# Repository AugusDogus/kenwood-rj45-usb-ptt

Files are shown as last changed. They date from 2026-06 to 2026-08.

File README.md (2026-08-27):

# kenwood-rj45-usb-ptt

USB push-to-talk adapter for Kenwood-style RJ45 handheld microphones such as KMC-30 / KMC-32 compatible mics.

## Why

The goal is a CB-radio-style handheld PTT mic for a computer, and nothing off the shelf does the whole job. USB PTT mics are desktop/gooseneck units, handheld dispatch mics with the right feel are not USB (XLR, RJ45, or radio-specific plugs) and need extra hardware, and USB handheld mics have no PTT switch. Level-triggered or software PTT is unreliable; the mic's physical switch should be the trigger.

This adapter closes that gap: plug in a cheap, widely available Kenwood-style RJ45 hand mic and the board shows up as a standard USB audio microphone plus a USB HID keyboard that holds F13 while PTT is pressed, so any app with a push-to-talk keybind (Discord, Mumble, dispatch software) works with no drivers or custom software.

Rev A is a PCBWay-assemblable board. It uses a Seeed XIAO RP2040 module for USB and firmware, an MCP6002 analog front-end for the microphone, and an RJ45 jack for the hand mic.

## What To Upload To PCBWay

Use the release assets from `v0.1.0`, or the matching files in `manufacturing/revA/`:

- `kenwood-rj45-usb-ptt-revA-fabrication.zip` for PCB fabrication Gerbers/drill
- `BOM_pcbway_revA.csv` for assembly BOM
- `positions_revA.csv` for pick-and-place / centroid
- `PCBWAY_NOTES_revA.md` for assembly notes

`manufacturing/revA/ORDER_INSTRUCTIONS.md` has the same checklist in upload order.

## Current Status

- KiCad DRC: 0 violations
- Unconnected items: 0
- Firmware: not implemented yet
- First hardware spin: order a small quantity only

## Repository Layout

- `hardware/kicad/` - KiCad 9 project, board, schematic, and vendored footprint/symbol libraries
- `manufacturing/revA/` - PCBWay-ready fabrication and assembly outputs
- `firmware/` - firmware plan and future XIAO RP2040 code
- `tools/` - board generation helper used for Rev A
- `docs/` - design/order notes

## Rev A Architecture

```text
Kenwood RJ45 hand mic
  mic audio -> electret bias -> MCP6002 preamp -> XIAO RP2040 ADC -> USB audio microphone
  PTT       -> debounced GPIO -> XIAO RP2040 USB HID keyboard -> F13 while held

Computer USB-C -> exposed USB-C connector on Seeed XIAO RP2040 module
```

RJ45 pin 2 is intentionally left open. Some Kenwood-style radios provide accessory power on that pin, but Rev A does not feed voltage into it.

## Open In KiCad

Open:

`hardware/kicad/radio-mic-usb-ptt.kicad_pro`

The KiCad project uses project-relative library tables, so it should open from this repo without global library setup.

## Regenerate Rev A Board

The final board file is already generated and routed. To regenerate the unrouted board from the helper script:

```sh
NO_ROUTES=1 python3 tools/generate_revA_board.py
```

Then autoroute/import in KiCad or with the MCP tooling. Do not run multi-attempt autorouting unless you explicitly want multiple confirmation prompts.

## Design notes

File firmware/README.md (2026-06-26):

# Firmware Plan

Target: Seeed XIAO RP2040.

Required USB functions:

- USB HID keyboard: hold `F13` while `PTT_GPIO` is active.
- USB Audio Class microphone: stream ADC samples from `MIC_ADC`.

Rev A pin mapping:

| Function | XIAO pin | RP2040 GPIO | Schematic net |
| --- | --- | ---: | --- |
| Mic ADC | D0 | GPIO26 / ADC0 | `MIC_ADC` |
| PTT input | D6 | GPIO0 | `PTT_GPIO` |
| Optional UP input | D7 | GPIO1 | `UP_GPIO` |
| Optional DOWN input | D8 | GPIO2 | `DOWN_GPIO` |
| PTT/status LED | D10 | GPIO3 | `PTT_LED_DRIVE` |

Recommended firmware stack:

- Pico SDK
- TinyUSB device stack
- Composite USB descriptors for Audio Class + HID keyboard

PTT behavior:

```c
if (ptt_pressed && !held) {
    hid_keyboard_press(F13);
    held = true;
}

if (!ptt_pressed && held) {
    hid_keyboard_release(F13);
    held = false;
}
```

Audio behavior:

- Sample ADC0 at a speech-oriented rate such as 16 kHz or 48 kHz.
- Center samples around the ADC midscale produced by the analog `VREF` circuit.
- Present mono 16-bit PCM over USB Audio Class.

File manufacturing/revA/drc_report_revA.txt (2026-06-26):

** Drc report for radio-mic-usb-ptt.kicad_pcb **
** Created on 2026-06-25T22:26:27 **
** Report includes: Errors, Warnings **

** Found 0 DRC violations **

** Found 0 unconnected pads **

** Found 0 Footprint errors **

** Ignored checks **
    - Footprint has no courtyard defined
    - Track endpoint not centered on via
    - Tuning profile track geometries
    - Footprint doesn't match symbol's footprint filters
    - PTH inside courtyard
    - NPTH inside courtyard
    - Footprint component type doesn't match footprint pads

** End of Report **

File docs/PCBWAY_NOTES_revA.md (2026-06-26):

# PCBWay Rev A Assembly Notes

## Assembly Intent

This is intended as a fully assembled PCBWay PCBA order. The Seeed XIAO RP2040 is treated as an SMD castellated module, not as a hand-soldered development board.

## Do Not Populate / Do Not Install

- Rev A does not connect RJ45 pin 2 to anything. This intentionally avoids feeding power into an unknown microphone accessory-power pin.
- There are no DNP components in the final Rev A PCBWay BOM.

## Through-Hole Parts

- `J1` is an RJ45 through-hole connector footprint.
- `TP1`-`TP4` are test pads and can be omitted if PCBWay treats them as through-hole assembly cost adders.
- Mounting holes are NPTH and should not be plated.

## Placement Intent

- RJ45 mic jack should sit on the left edge of the board.
- XIAO RP2040 USB-C connector should be exposed on the opposite edge.
- Keep `MIC_RAW`, `MIC_AC`, `VREF`, and `MIC_ADC` traces short and away from digital GPIO where practical.
- Put `C5` close to `U2` VDD/VSS.
- Put `C3` close to the XIAO ADC input pad.

## Required Order Files

PCBWay requests these for PCBA:

- Gerbers
- Drill files
- BOM CSV/XLSX
- Pick-and-place / centroid / XYRS file

Use `manufacturing/revA/BOM_pcbway_revA.csv` as the assembly BOM for Rev A.

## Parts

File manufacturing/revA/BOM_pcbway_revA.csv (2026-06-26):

Line | Qty | References | Value | Footprint | Type | Manufacturer | Manufacturer Part Number | Notes
1 | 1 | U1 | Seeed XIAO RP2040 | XIAO-RP2040-SMD | SMD module | Seeed Studio | 102010428 | Castellated module; confirm PCBWay can source or consign
2 | 1 | U2 | MCP6002T-E/MS | MSOP-8_3x3mm_P0.65mm | SMD | Microchip | MCP6002T-E/MS | Dual rail-to-rail op amp
3 | 1 | J1 | KMC RJ45 MIC | RJ45_Amphenol_RJHSE5380 | Through-hole | Amphenol | RJHSE-5380 | 8P8C RJ45 jack
4 | 1 | R1 | 2.2k | R_0603_1608Metric | SMD | Generic | 0603 1% | Electret mic bias
5 | 3 | R2 R3 R13 | 100k | R_0603_1608Metric | SMD | Generic | 0603 1% | VREF divider and input bias
6 | 2 | R4 R7 | 10k | R_0603_1608Metric | SMD | Generic | 0603 1% | Gain resistor and PTT pull-up
7 | 1 | R5 | 200k | R_0603_1608Metric | SMD | Generic | 0603 1% | Preamp feedback gain resistor
8 | 3 | R6 R8 R11 | 1k | R_0603_1608Metric | SMD | Generic | 0603 1% | GPIO/ADC/LED series resistors
9 | 2 | C1 C2 | 1uF | C_0603_1608Metric | SMD | Generic | 0603 X5R/X7R | Audio coupling and VREF filter
10 | 1 | C3 | 1nF | C_0603_1608Metric | SMD | Generic | 0603 C0G/X7R | ADC low-pass filter
11 | 2 | C4 C5 | 100nF | C_0603_1608Metric | SMD | Generic | 0603 X7R | PTT debounce and op-amp decoupling
12 | 1 | D1 | PTT_LED | LED_0603_1608Metric | SMD | Generic | 0603 LED | Firmware-driven status LED

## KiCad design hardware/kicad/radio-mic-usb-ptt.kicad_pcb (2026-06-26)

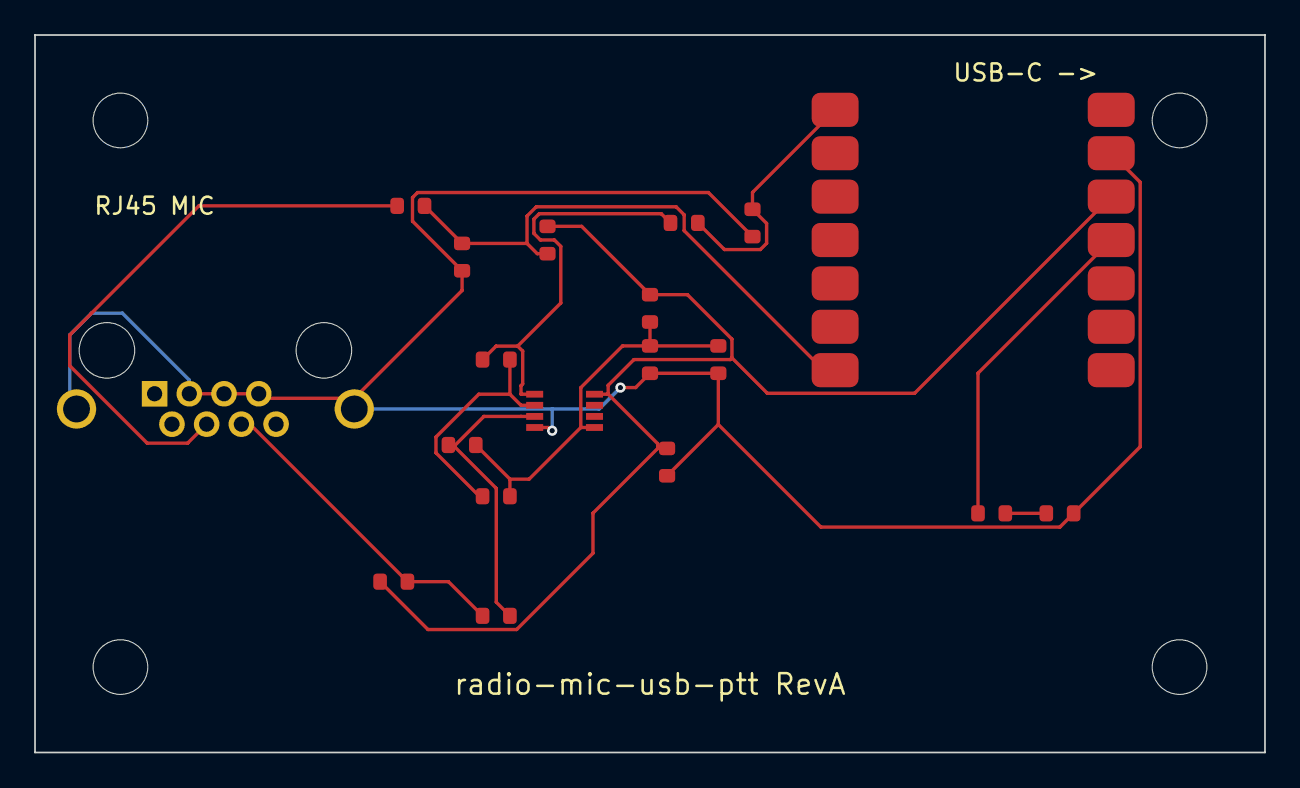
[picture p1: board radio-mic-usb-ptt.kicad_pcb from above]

Board: 2 copper layers, 72.0 x 42.0 mm, 23 parts (0 on the bottom side), 12 nets.

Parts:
C1, C2: 1uF; C_0603_1608Metric
C3: 1nF; C_0603_1608Metric
C4, C5: 100nF; C_0603_1608Metric
D1: PTT_LED; LED_0603_1608Metric
H1, H2, H3, H4: MountingHole_3.2mm
J1: KMC RJ45 MIC; RJ45_Amphenol_RJHSE5380
R1: 2.2k; R_0603_1608Metric
R2, R3, R13: 100k; R_0603_1608Metric
R4, R7: 10k; R_0603_1608Metric
R5: 200k; R_0603_1608Metric
R6, R8, R11: 1k; R_0603_1608Metric
U1: Seeed XIAO RP2040; XIAO-RP2040-SMD
U2: MCP6002T-E/MS; MSOP-8_3x3mm_P0.65mm

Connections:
+3V3: C5.1, R1.1, R2.1, R7.1, U1.12, U2.8
GND: C2.2, C3.2, C4.2, C5.2, D1.2, J1.3, J1.5, J1.7, J1.SH, R3.2, U1.13, U2.4
LED_A: D1.1, R11.2
MIC_AC: C1.2, R13.1, U2.3
MIC_ADC: C3.1, R6.2, U1.1
MIC_AMP: R5.1, R6.1, U2.1
MIC_RAW: C1.1, J1.6, R1.2
NINV: R4.1, R5.2, U2.2
PTT_GPIO: C4.1, R7.2, R8.2, U1.7
PTT_LED_DRIVE: R11.1, U1.11
PTT_RAW: J1.4, R8.1
VREF: C2.1, R2.2, R3.1, R4.2, R13.2, U2.5

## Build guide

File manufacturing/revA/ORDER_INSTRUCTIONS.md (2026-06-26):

# PCBWay Rev A Order Instructions

Upload these files for a PCB + assembly order:

- PCB fabrication: `kenwood-rj45-usb-ptt-revA-fabrication.zip` release asset, or zip the files in `gerbers/` and `drill/`
- Assembly BOM: `BOM_pcbway_revA.csv`
- Pick-and-place / centroid: `positions_revA.csv`
- Notes: `PCBWAY_NOTES_revA.md`

Important assembly notes:

- Rev A is top-side assembly only.
- RJ45 pin 2 is intentionally left open.
- There are no DNP parts in the final Rev A BOM.
- Confirm whether PCBWay can source `U1` Seeed Studio XIAO RP2040, MPN `102010428`. If not, order it as consigned/kitted assembly or revise to a bare RP2040 design later.

Validation status:

- KiCad 9.0.9 DRC was run.
- DRC has zero violations and zero unconnected items.

Do not order large quantities from Rev A. This is the first hardware spin and still needs mic pinout and firmware validation.

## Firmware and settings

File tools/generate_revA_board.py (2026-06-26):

#!/usr/bin/env python3
from pathlib import Path
import os
from uuid import uuid4

ROOT = Path(__file__).resolve().parents[1]
BOARD = ROOT / "hardware" / "kicad" / "radio-mic-usb-ptt.kicad_pcb"

NETS = {
    "": 0,
    "GND": 1,
    "+3V3": 2,
    "MIC_RAW": 3,
    "MIC_AC": 4,
    "VREF": 5,
    "NINV": 6,
    "MIC_AMP": 7,
    "MIC_ADC": 8,
    "PTT_RAW": 9,
    "PTT_GPIO": 10,
    "UP_RAW": 11,
    "UP_GPIO": 12,
    "DOWN_RAW": 13,
    "DOWN_GPIO": 14,
    "PTT_LED_DRIVE": 15,
    "LED_A": 16,
    "MIC_PWR": 17,
    "SPARE_B": 18,
}


def u():
    return str(uuid4())


def net(name):
    return f'(net {NETS[name]} "{name}")' if name else '(net 0 "")'


def pad_net(name):
    return f'(net {NETS[name]} "{name}")' if name else ''


def xy(n):
    return f"{n:.3f}".rstrip("0").rstrip(".")


def prop(name, value, x, y, layer="F.Fab", hide=True):
    h = " hide" if hide else ""
    return f'''    (property "{name}" "{value}" (at {xy(x)} {xy(y)} 0) (layer "{layer}"){h}
      (effects (font (size 1 1) (thickness 0.15)))
    )'''


def fp_header(lib, name, ref, value, x, y, rot=0, attr="smd"):
    # Footprints are embedded directly in the board. Leaving off the library
    # nickname avoids KiCad DRC warnings about generated geometry not matching
    # a separate footprint library copy.
    return f'''  (footprint "{name}"
    (layer "F.Cu")
    (uuid "{u()}")
    (at {xy(x)} {xy(y)} {rot})
{prop("Reference", ref, 0, -1.6, "F.Fab", True)}
{prop("Value", value, 0, 1.6, "F.Fab", True)}
    (attr {attr})'''


def fp_end():
    return "  )"


def two_pad(lib, name, ref, value, x, y, nets, rot=0, dnp=False):
    attr = "smd" + (" dnp" if dnp else "")
    lines = [fp_header(lib, name, ref, value, x, y, 0, attr)]
    if rot == 90:
        p1 = (0, -0.8, 90)
        p2 = (0, 0.8, 90)
    else:
        p1 = (-0.8, 0, 0)
        p2 = (0.8, 0, 0)
    lines += [
        '    (fp_rect (start -1.55 -0.75) (end 1.55 0.75) (stroke (width 0.05) (type default)) (fill none) (layer "F.CrtYd") (uuid "%s"))' % u(),
        f'    (pad "1" smd roundrect (at {xy(p1[0])} {xy(p1[1])} {p1[2]}) (size 0.8 0.95) (layers "F.Cu" "F.Paste" "F.Mask") (roundrect_rratio 0.25) {pad_net(nets[0])} (uuid "{u()}"))',
        f'    (pad "2" smd roundrect (at {xy(p2[0])} {xy(p2[1])} {p2[2]}) (size 0.8 0.95) (layers "F.Cu" "F.Paste" "F.Mask") (roundrect_rratio 0.25) {pad_net(nets[1])} (uuid "{u()}"))',
        fp_end(),
    ]
    return "\n".join(lines)


def testpoint(ref, value, x, y, netname):
    return f'''  (footprint "TestPoint_THTPad_D1.5mm"
    (layer "F.Cu")
    (uuid "{u()}")
    (at {xy(x)} {xy(y)} 0)
{prop("Reference", ref, 0, -1.5)}
{prop("Value", value, 0, 1.5, "F.Fab", True)}
    (attr exclude_from_pos_files)
    (pad "1" thru_hole circle (at 0 0) (size 1.5 1.5) (drill 0.7) (layers "*.Cu" "*.Mask") {pad_net(netname)} (uuid "{u()}"))
  )'''


def mounting(ref, x, y):
    return f'''  (footprint "MountingHole_3.2mm"
    (layer "F.Cu")
    (uuid "{u()}")
    (at {xy(x)} {xy(y)} 0)
{prop("Reference", ref, 0, -2)}
{prop("Value", "MountingHole_3.2mm", 0, 2, "F.Fab", True)}
    (attr exclude_from_pos_files exclude_from_bom)
    (pad "" np_thru_hole circle (at 0 0) (size 3.2 3.2) (drill 3.2) (layers "*.Cu" "*.Mask") (uuid "{u()}"))
  )'''


def rj45():
    x, y = 7, 21
    pad_defs = [
        ("1", 0, 0, "rect", ""),
        ("3", 2.032, 0, "circle", "GND"),
        ("5", 4.064, 0, "circle", "GND"),
        ("7", 6.096, 0, "circle", "GND"),
        ("2", 1.016, 1.78, "circle", ""),
        ("4", 3.048, 1.78, "circle", "PTT_RAW"),
        ("6", 5.08, 1.78, "circle", "MIC_RAW"),
        ("8", 7.112, 1.78, "circle", ""),
    ]
    lines = [fp_header("Connector_RJ", "RJ45_Amphenol_RJHSE5380", "J1", "KMC RJ45 MIC", x, y, 0, "through_hole")]
    lines += [
        '    (fp_rect (start -6.22 -8.5) (end 13.34 8.25) (stroke (width 0.05) (type default)) (fill none) (layer "F.CrtYd") (uuid "%s"))' % u(),
    ]
    for num, px, py, shape, netname in pad_defs:
        lines.append(f'    (pad "{num}" thru_hole {shape} (at {xy(px)} {xy(py)} 0) (size 1.5 1.5) (drill 0.89) (layers "*.Cu" "*.Mask") {pad_net(netname)} (uuid "{u()}"))')
    lines += [
        f'    (pad "" np_thru_hole circle (at -2.79 -2.54 0) (size 3.25 3.25) (drill 3.25) (layers "*.Cu" "*.Mask") (uuid "{u()}"))',
        f'    (pad "" np_thru_hole circle (at 9.91 -2.54 0) (size 3.25 3.25) (drill 3.25) (layers "*.Cu" "*.Mask") (uuid "{u()}"))',
        f'    (pad "SH" thru_hole circle (at 11.69 0.89 0) (size 2.3 2.3) (drill 1.57) (layers "*.Cu" "*.Mask") {pad_net("GND")} (uuid "{u()}"))',
        f'    (pad "SH" thru_hole circle (at -4.57 0.89 0) (size 2.3 2.3) (drill 1.57) (layers "*.Cu" "*.Mask") {pad_net("GND")} (uuid "{u()}"))',
        fp_end(),
    ]
    return "\n".join(lines)


def xiao():
    x, y = 46, 22.5
    nets = {
        "1": "MIC_ADC", "7": "PTT_GPIO",
        "11": "PTT_LED_DRIVE", "12": "+3V3", "13": "GND", "18": "GND", "20": "GND",
    }
    pads = [
        ("1", 0.835, -18.12, 2.75, 2, 0), ("2", 0.835, -15.58, 2.75, 2, 0),
        ("3", 0.835, -13.04, 2.75, 2, 0), ("4", 0.835, -10.5, 2.75, 2, 0),
        ("5", 0.835, -7.96, 2.75, 2, 0), ("6", 0.835, -5.42, 2.75, 2, 0),
        ("7", 0.835, -2.88, 2.75, 2, 0), ("8", 17, -2.88, 2.75, 2, 0),
        ("9", 17, -5.42, 2.75, 2, 0), ("10", 17, -7.96, 2.75, 2, 0),
        ("11", 17, -10.5, 2.75, 2, 0), ("12", 17, -13.04, 2.75, 2, 0),
        ("13", 17, -15.58, 2.75, 2, 0), ("14", 17, -18.12, 2.75, 2, 0),
    ]
    lines = [fp_header("Seeed_Studio_XIAO_Series", "XIAO-RP2040-SMD", "U1", "Seeed XIAO RP2040", x, y, 0, "smd")]
    lines += [
        '    (fp_rect (start 0 -21) (end 17.8 0) (stroke (width 0.05) (type default)) (fill none) (layer "F.CrtYd") (uuid "%s"))' % u(),
    ]
    for num, px, py, sx, sy, circle in pads:
        shape = "circle" if circle else "roundrect"
        rr = "" if circle else "(roundrect_rratio 0.25)"
        lines.append(f'    (pad "{num}" smd {shape} (at {xy(px)} {xy(py)} 0) (size {xy(sx)} {xy(sy)}) (layers "F.Cu" "F.Paste" "F.Mask") {rr} {pad_net(nets.get(num, ""))} (uuid "{u()}"))')
    lines.append(fp_end())
    return "\n".join(lines)


def msop():
    x, y = 31, 22
    nets = {"1":"MIC_AMP", "2":"NINV", "3":"MIC_AC", "4":"GND", "5":"VREF", "6":"", "7":"", "8":"+3V3"}
    pads = [("1",-1.75,-0.975),("2",-1.75,-0.325),("3",-1.75,0.325),("4",-1.75,0.975),("5",1.75,0.975),("6",1.75,0.325),("7",1.75,-0.325),("8",1.75,-0.975)]
    lines = [fp_header("radio-mic-usb-ptt", "MSOP-8_3x3mm_P0.65mm", "U2", "MCP6002T-E/MS", x, y, 0, "smd")]
    lines += ['    (fp_rect (start -2.55 -1.85) (end 2.55 1.85) (stroke (width 0.05) (type default)) (fill none) (layer "F.CrtYd") (uuid "%s"))' % u()]
    for num, px, py in pads:
        lines.append(f'    (pad "{num}" smd rect (at {xy(px)} {xy(py)} 0) (size 1 0.4) (layers "F.Cu" "F.Paste" "F.Mask") {pad_net(nets[num])} (uuid "{u()}"))')
    lines.append(fp_end())
    return "\n".join(lines)
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
